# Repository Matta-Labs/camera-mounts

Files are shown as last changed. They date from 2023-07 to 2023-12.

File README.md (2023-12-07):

<!-- Improved compatibility of back to top link: See: https://github.com/othneildrew/Best-README-Template/pull/73 -->

<!--
*** Thanks for checking out the Best-README-Template. If you have a suggestion
*** that would make this better, please fork the repo and create a pull request
*** or simply open an issue with the tag "enhancement".
*** Don't forget to give the project a star!
*** Thanks again! Now go create something AMAZING! :D
-->

<!-- PROJECT SHIELDS -->
<!--
*** I'm using markdown "reference style" links for readability.
*** Reference links are enclosed in brackets [ ] instead of parentheses ( ).
*** See the bottom of this document for the declaration of the reference variables
*** for contributors-url, forks-url, etc. This is an optional, concise syntax you may use.
*** https://www.markdownguide.org/basic-syntax/#reference-style-links
-->
[][contributors-url]
[][forks-url]
[][stars-url]
[][issues-url]
[][license-url]
[][linkedin-url]

<!-- PROJECT LOGO -->
<br />
<div align="center">
  <a href="https://github.com/Matta-Labs/camera-mounts">
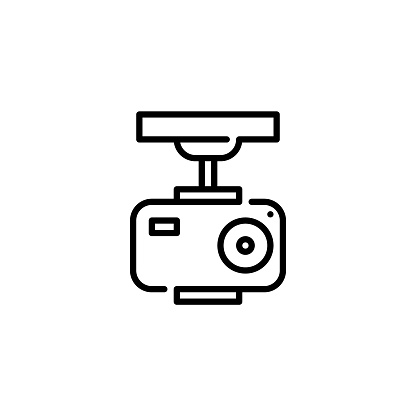
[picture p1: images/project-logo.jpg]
    
  </a>

<h3 align="center">Camera Mounts</h3>

  <p align="center">
    Welcome to the 3D Printer Camera Mounts GitHub repository! This project aims to provide a collection of camera mounts specifically for 3D printers. Attaching a camera to your printer allows for remote monitoring through OctoPrint or Klipper, time-lapse recording, and overall enhanced control of your printing processes.
    <br />
    <br />
    <a href="https://github.com/Matta-Labs/camera-mounts/issues">Report Problems</a>
    ·
    <a href="https://github.com/Matta-Labs/camera-mounts/issues">Request New Mounts!</a>
  </p>
</div>

<!-- ABOUT THE PROJECT -->
## About The Project ⚡️

<div  align="center" >
  Data engine
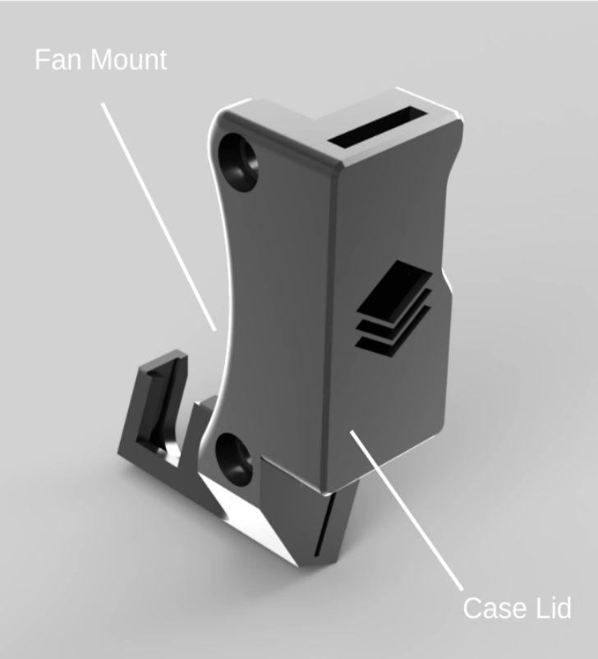
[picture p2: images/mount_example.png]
Mount example
  
  Close-up
</div>
<br />

At <a href="https://matta.ai"><strong>Matta</strong></a>, we use computer vision and AI to turbocharge 3D printing. Our work often results in the generation of printable hardware to allow cameras to be mounted to 3D printers.
<br />
<br />
We thought it would be helpful to the community to release these into the wild - and build an open source repository where new designs/improvements can be shared! 
<br />
<br />

<p align="right">(<a href="#readme-top">back to top</a>)</p>

### Introduction 🏁

Cameras mounted on 3D printers can be incredibly useful for various purposes. Whether you want to closely monitor your print progress, create stunning time-lapse videos, or remotely check on your printer's status, these 3D-printable camera mounts will come in handy. This repository serves as a hub for sharing various camera mount designs contributed by developers and designers in the community.
<br /><br />

### Built With 🛠️

[][Fusion-url]

<p align="right">(<a href="#readme-top">back to top</a>)</p>

<!-- USAGE EXAMPLES -->
## Usage ⚡️

The repo is broken-up into 3D printer brands. Navigate the repo to find your printer model, and browse the ReadMe's for printing/installation instruction. 
<br />
<br />
📸 Print, install and enjoy! Please leave feedback in FEEDBACK.md file within each mount directory.
<br />
<br />
All files should be accompanied by relevant documentation - raise an issue if not! 🚩
<p align="right">(<a href="#readme-top">back to top</a>)</p>

<!-- CONTRIBUTING -->
## Contributing 👏🏼

Contributions are what make the open source community such an amazing place to learn, inspire, and create. Any contributions you make are **greatly appreciated**.

If you have any exisiting camera mounts you are willing to share with the community, please do! We want to create the largest open source repo of 3D printer camera mounts on the internet! 

1. Fork the Project
2. Create a Branch for your Contribution (`git checkout -b Ultimaker-S5`)
3. Commit your Changes (`git commit -m 'Added nozzle mount for Ultimaker S5'`)
4. Push to the Branch (`git push origin Ultimaker-S5`)
5. Open a Pull Request

### Contribution Steps 💡

1. **Upload STL/STEP Files:** Upload or provide links to the STL/STEP files of the shared/developed camera mounts
2. **Camera Mount Demonstration:** Include images and GIFs demonstrating the installation and usage of the camera mounts.
3. **Document improvements you want to see:** If you know of any shortcomings of your designs, raise them in Issues! Someone may already have a solution for you!

<p align="right">(<a href="#readme-top">back to top</a>)</p>

<!-- ROADMAP -->
## Roadmap 🚴🏼‍♂️

- [x] Prusa
  - [x] i3 MK3S
    - [x] Nozzle camera
    - [ ] Bed camera

- [x] Creality
  - [x] Ender 3/Ender 3 Pro
    - [x] Nozzle camera
    - [ ] Bed camera
  - [x] Ender S1
    - [x] Nozzle camera
    - [ ] Bed camera
  - [x] CR-20
    - [x] Nozzle camera
    - [ ] Bed camera
- [ ] Ultimaker
- [ ] Voron
- [ ] Raise3D
- [ ] RatRig
- [ ] Makerbot
- [ ] BCN

See the [open issues](https://github.com/Matta-Labs/camera-mounts/issues) for a full list of proposed mount designs (and known issues).

<p align="right">(<a href="#readme-top">back to top</a>)</p>

<!-- LICENSE -->
## License 📄

Distributed under the MIT License. See `LICENSE.txt` for more information.

<p align="right">(<a href="#readme-top">back to top</a>)</p>

<!-- MORE ABOUT MATTA -->
## More About Matta 🔷

<div  align="center" >
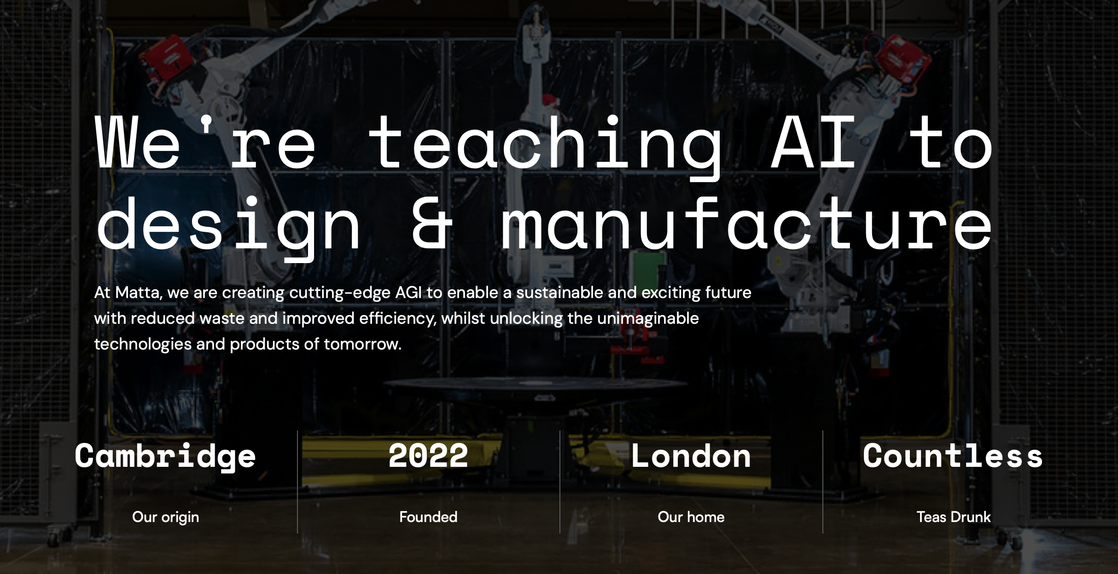
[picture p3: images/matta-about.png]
Data engine
  
</div>

At <a href="https://matta.ai"><strong>Matta</strong></a>, we are building AI to push the boundaries of manufacturing. We train neural networks using vision to become manufacturing copilots, enabling next-generation error correction, material qualitification and part QC.

<a href="https://matta.ai/greymatta"><strong>Check out our first-iteration AI, Grey-1</strong></a>

<!-- CONTACT -->
## Contact 📞

Team Matta - [@mattaai](https://twitter.com/mattaai) - hello@matta.ai

Project Link: [https://github.com/Matta-Labs/camera-mounts](https://github.com/Matta-Labs/camera-mounts)

<p align="right">(<a href="#readme-top">back to top</a>)</p>

<!-- ACKNOWLEDGMENTS -->
## Acknowledgments

* [Complex Additive Materials Group, University of Cambridge](https://github.com/cam-cambridge)

<p align="right">(<a href="#readme-top">back to top</a>)</p>

<!-- MARKDOWN LINKS & IMAGES -->
<!-- https://www.markdownguide.org/basic-syntax/#reference-style-links -->
[contributors-shield]: https://img.shields.io/github/contributors/Matta-Labs/camera-mounts.svg?style=for-the-badge
[contributors-url]: https://github.com/Matta-Labs/camera-mounts/graphs/contributors
[forks-shield]: https://img.shields.io/github/forks/Matta-Labs/camera-mounts.svg?style=for-the-badge
[forks-url]: https://github.com/Matta-Labs/camera-mounts/network/members
[stars-shield]: https://img.shields.io/github/stars/Matta-Labs/camera-mounts.svg?style=for-the-badge
[stars-url]: https://github.com/Matta-Labs/camera-mounts/stargazers
[issues-shield]: https://img.shields.io/github/issues/Matta-Labs/camera-mounts.svg?style=for-the-badge
[issues-url]: https://github.com/Matta-Labs/camera-mounts/issues
[license-shield]: https://img.shields.io/github/license/Matta-Labs/camera-mounts.svg?style=for-the-badge
[license-url]: https://github.com/Matta-Labs/camera-mounts/blob/master/LICENSE.txt
[linkedin-shield]: https://img.shields.io/badge/-LinkedIn-black.svg?style=for-the-badge&logo=linkedin&colorB=555
[linkedin-url]: https://www.linkedin.com/company/mattaai
[de-gif]: images/data-engine.gif
[Fusion.360]: https://img.shields.io/badge/Autodesk-Fusion%20360-FC6E26?style=for-the-badge&logo=autodesk&logoColor=white
[Fusion-url]: https://autodesk.com/products/fusion360/overview

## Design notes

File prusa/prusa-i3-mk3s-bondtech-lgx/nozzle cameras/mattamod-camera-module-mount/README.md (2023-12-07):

<!-- WHEN SHARING MOUNTS, FILL OUT THIS TEMPLATE AND ADD AS 'README.md' IN MOUNT FOLDER-->

<!-- HEADER -->
<br />
<div align="center">
  <a href="https://github.com/Matta-Labs/camera-mounts">
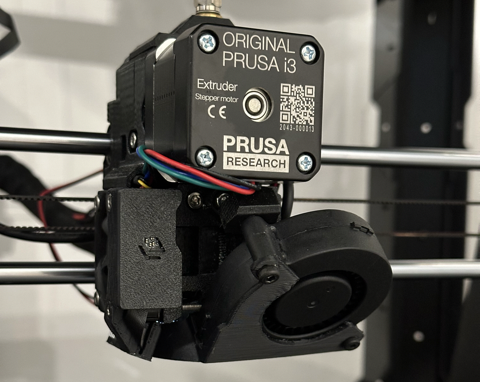
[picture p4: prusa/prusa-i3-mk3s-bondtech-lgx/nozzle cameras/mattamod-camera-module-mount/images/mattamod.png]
    
  </a>

<h3 align="center">Mount: MattaMod Prusa i3 MK3S Camera Module Mount (for BondTech LGX Extruder)</h3>

  <p align="center">
    This is a simple, two-piece mount to allow a cheap, off-the-shelf camera module to work as a nozzle camera for the Prusa i3 MK3S 3D printer fitted with the BondTech LGX extruder. 
    <br />
    <br />
    <a href="https://github.com/Matta-Labs/camera-mounts/issues">Report Problems</a>

  </p>
</div>

<!-- ABOUT THE PROJECT -->
## Mount Details

<b>Compatible Printer:</b> Prusa i3 MK3S (with BondTech LGX Extruder)
<br />
<br />
<b>Compatible Camera:</b> OV5640 Camera Module (66º Fixed Focus HD 5MP) - https://shorturl.at/bfxX8
<br />
<b>Other useful components:</b> Longer camera cable - https://shorturl.at/sCEY2, Heatsinks for camera module - https://shorturl.at/jQX79
<br />

### Built With 🛠️

* [][Fusion-url]

<!-- INSTALLATION -->
## Installation ⚡️

We recommend printing in ASA, for thermal resistance, PLA will quickly warp due to the heat of the camera.

<p>
  <b>Slicing/Printing</b>

  1. Slice with normal or tree supports, with the base of the mount flat against the bed.
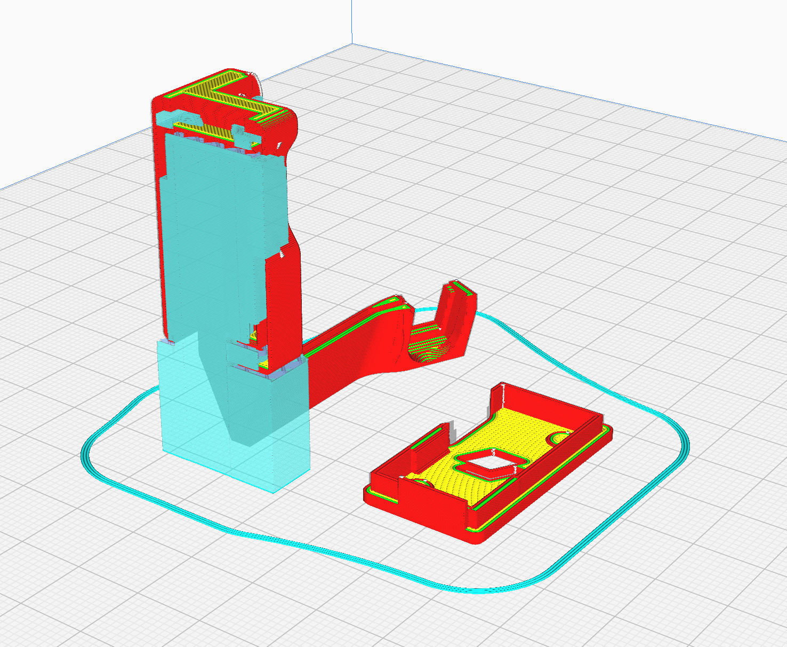
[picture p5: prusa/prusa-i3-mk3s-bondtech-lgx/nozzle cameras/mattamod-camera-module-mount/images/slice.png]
Slicing orientation
  
  2. We usually recommend a layer height of 0.2mm, and a brim for bed adhesion.
  <br>
  3. Print in ASA.
  <br />
  <br />
</p>
<p>
  <b>Installation</b>

  1. Carefully insert the camera unit into the housing, and press down until you feel a click.
  <br/>
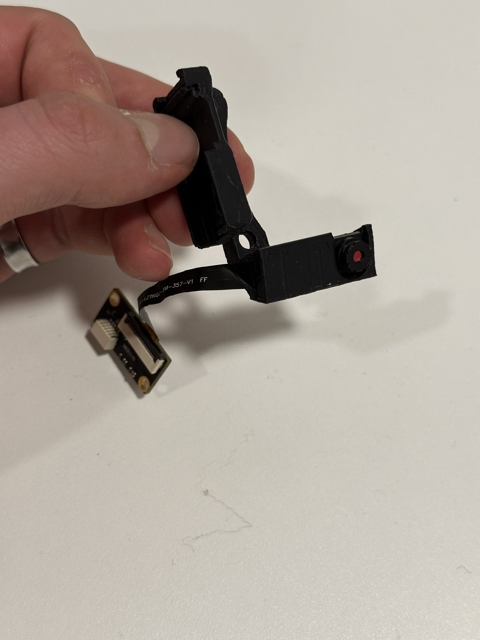
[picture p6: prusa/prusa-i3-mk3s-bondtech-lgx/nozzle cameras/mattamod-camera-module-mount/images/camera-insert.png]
Inserting camera unit
  
  <br/>
  2. Route the ribbon cable up into the board housing and carefully fold so that it is tucked behind the board
  <br/>
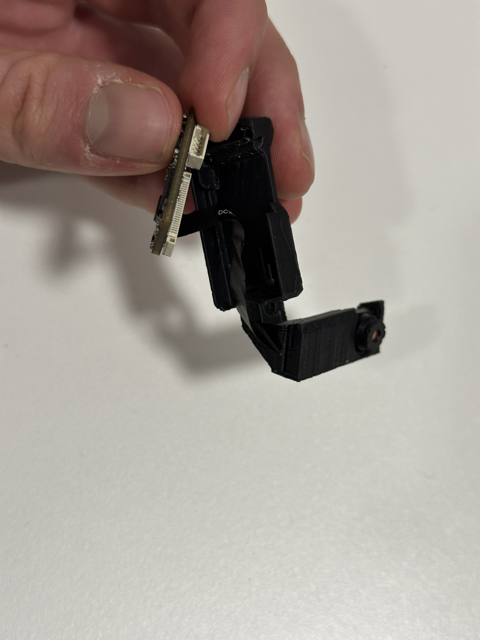
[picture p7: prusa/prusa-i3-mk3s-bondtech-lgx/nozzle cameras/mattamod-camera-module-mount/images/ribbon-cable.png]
Routing ribbon cable
  
  <br/>
  3. Click the board into place, and then cover with the case lid
  <br/>
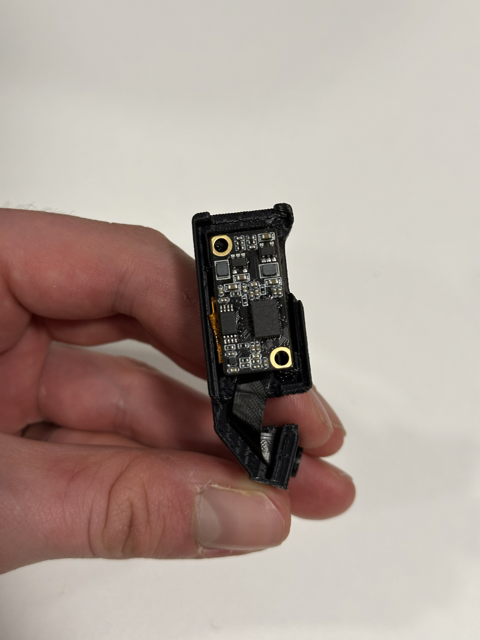
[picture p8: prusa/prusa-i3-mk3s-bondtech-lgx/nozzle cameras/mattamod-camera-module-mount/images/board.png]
Clipping board into mount
  
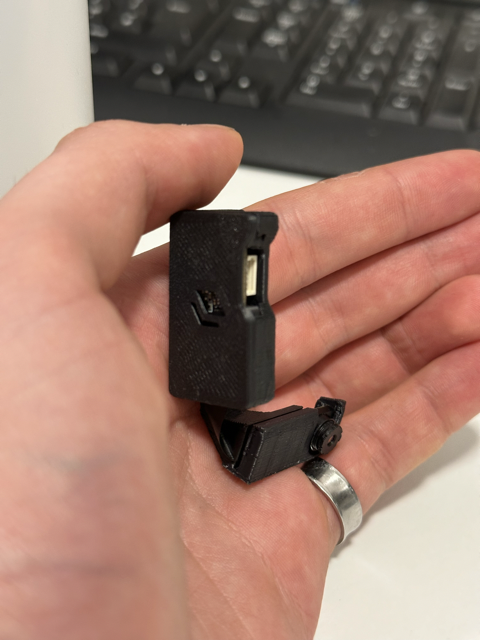
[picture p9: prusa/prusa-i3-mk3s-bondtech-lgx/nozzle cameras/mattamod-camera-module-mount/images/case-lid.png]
Clipping board into mount
  
  <br/>
  4. Add a 7x7x3mm heatsink to the back of the camera unit
  <br/>
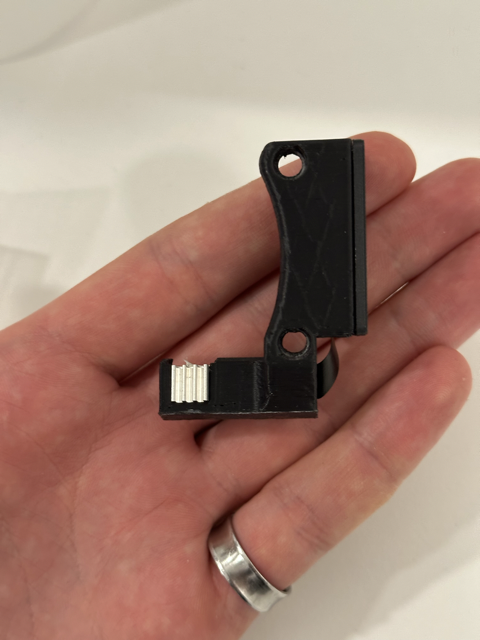
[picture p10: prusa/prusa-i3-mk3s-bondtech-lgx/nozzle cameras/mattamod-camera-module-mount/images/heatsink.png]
Adding heatsink
  
  <br/>
  5. Use two M3 20mm bolts to secure the mount to the right hand side of the hotend fan.
  <br/>
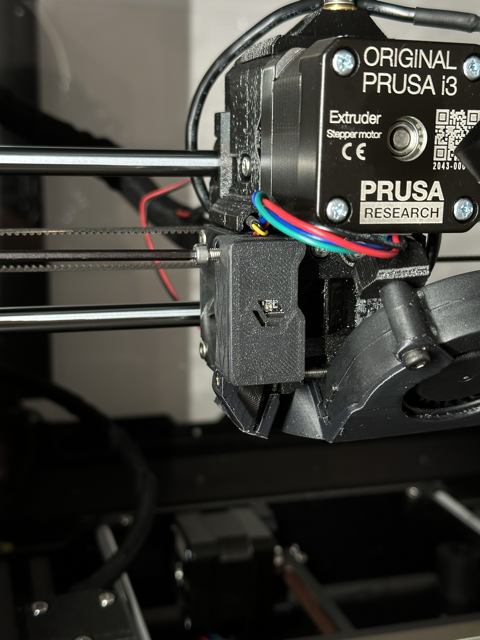
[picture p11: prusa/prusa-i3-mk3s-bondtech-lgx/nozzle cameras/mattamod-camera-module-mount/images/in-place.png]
Mount in place
  
  <br/>
  6. Route the camera cable as you wish, see our fs-cable-router or lgx-cable-router components for reference. We usually route the cable into the Prusa's cable sleeve for tidiness. The longer cable listed is helpful to ensure there is enough length to connect to your Pi/Laptop.
  <br />
</p>

<!-- Lighting -->
## Lighting (Example) 🔦

<p>

  The Prusa extruder occludes a lot of light, meaning the area under the nozzle is rather dark. To get around this, it is advantageous to build some kind of light source incident on the nozzle. 
  <br/>
  Below is an example of how we tackled this issue with our internal printers:

  <b>Required components:</b> Matta LED holder parts, 24 AWG wiring, Pre-wired LED - https://shorturl.at/gpvT9, Soldering Kit, Molex Crimp connector parts - https://shorturl.at/rvCX1, https://shorturl.at/mpruV

  1. Print LED holder in ASA. There are different versions of this for the standard and BondTech versions of the mount.
  <br/>
  <div>LED holder component</div>
  <br/>
  2. Solder the Pre-wired LED onto lengths of the 24 AWG wire, such that the wiring can be ran from the Einsey board, all the way to the nozzle.
  <br/> 
  <div>Wired LED</div>
  <br/>
  3. Use crimps to add the male Molex holder to the end of the LED wire
  <br/>
  <div>Molex head on LED cable</div>
  <br/>
  4. Connect the LED with the Molex connector to the highlighted, free port on the Einsey board.
  <br/>
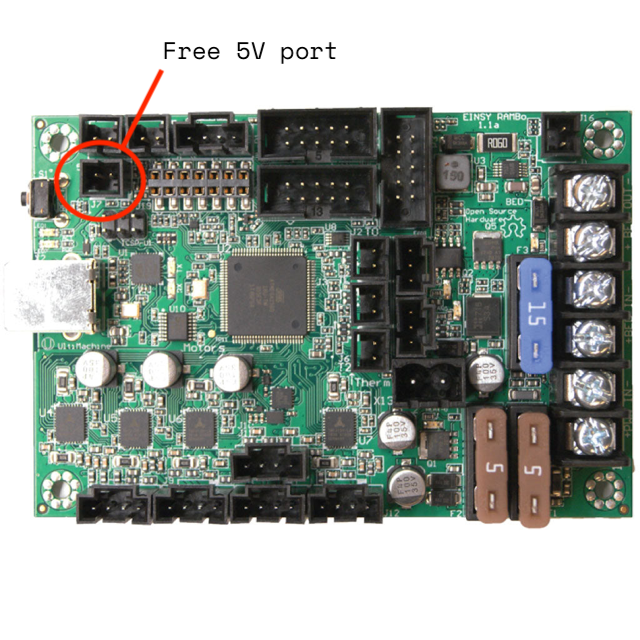
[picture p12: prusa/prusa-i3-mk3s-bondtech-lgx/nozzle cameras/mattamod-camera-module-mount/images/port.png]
Free port
  
  <br />
</p>

<br/>

📸 Print, install and enjoy! Please leave feedback for this mount in the appropriate FEEDBACK.md file.

<!-- LICENSE -->
## License 📄

Distributed under the MIT License. See `LICENSE.txt` for more information.

<!-- CONTACT -->
## Contact 📞

Tom Walker - [tomwalkr](https://github.com/tom-walkr) - tom@matta.ai

<!-- MARKDOWN LINKS & IMAGES -->
<!-- https://www.markdownguide.org/basic-syntax/#reference-style-links -->
[Fusion.360]: https://img.shields.io/badge/Autodesk-Fusion%20360-FC6E26?style=for-the-badge&logo=autodesk&logoColor=white
[Fusion-url]: https://autodesk.com/products/fusion360/overview

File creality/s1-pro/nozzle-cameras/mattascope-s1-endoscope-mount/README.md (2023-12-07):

<!-- WHEN SHARING MOUNTS, FILL OUT THIS TEMPLATE AND ADD AS 'README.md' IN MOUNT FOLDER-->

<!-- HEADER -->
<br />
<div align="center">
  <a href="https://github.com/Matta-Labs/camera-mounts">
    
  </a>

<h3 align="center">Mount: MattaScope S1 Endoscope Mount </h3>

  <p align="center">
    This is a simple, one-piece mount to allow a cheap, off-the-shelf endoscope to work as a nozzle camera for Creality Ender S1 printers (or printer with a Sprite Extruder)
    <br />
    <br />
    <a href="https://github.com/Matta-Labs/camera-mounts/issues">Report Problems</a>

  </p>
</div>

<!-- ABOUT THE PROJECT -->
## Mount Details

<b>Compatible Printer:</b> Creality Ender S1/S1 Pro (or anything with a Sprite Extruder)
<br />
<br />
<b>Compatible Camera:</b> Pancellent Auto Focus Endoscope 1944P HD Borescope Camera - https://shorturl.at/osMPY, https://shorturl.at/nquC0 
<br />

### Built With 🛠️

* [][Fusion-url]

<!-- INSTALLATION -->
## Installation ⚡️

Mount installation is simple - requiring no other components or tools! We recommend printing in ASA, for thermal resistance, PLA will quickly warp due to the heat of the camera.

<p>
  <b>Slicing/Printing</b>

  1. Slice with normal or tree supports, with the mounting plate flat against the bed.
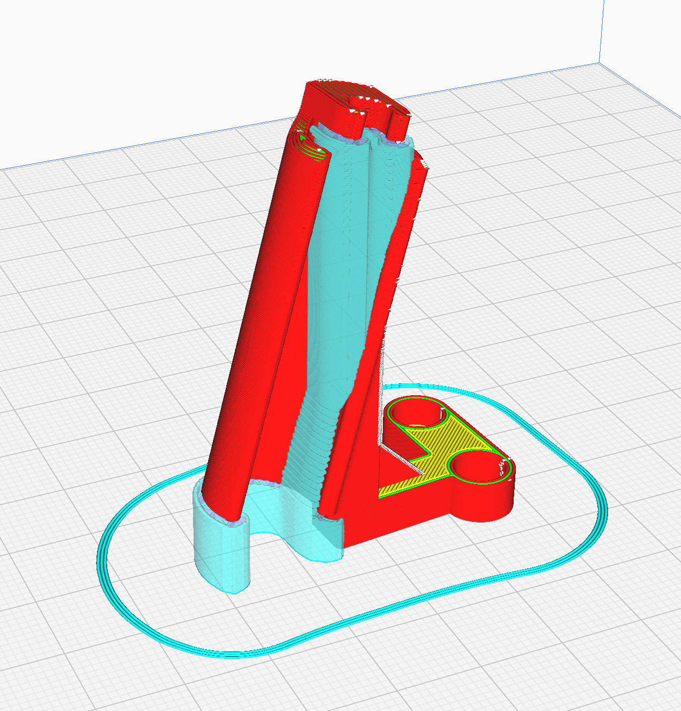
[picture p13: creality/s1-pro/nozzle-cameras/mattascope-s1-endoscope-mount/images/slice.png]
Slicing orientation
  
  2. We usually recommend a layer height of 0.2mm, and a brim for bed adhesion.
  <br>
  3. Print in ASA for longevity, but PLA works fine also.
  <br />
  <br />
</p>
<p>
  <b>Installation</b>

  1. Clip the endoscope into the mount, and secure the cable by pushing it into the clasp.
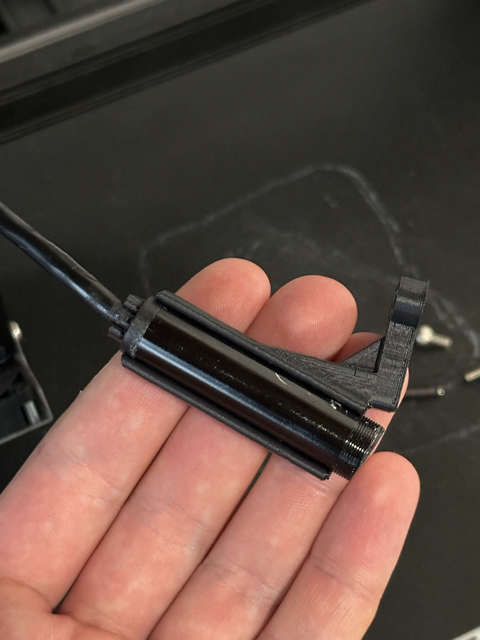
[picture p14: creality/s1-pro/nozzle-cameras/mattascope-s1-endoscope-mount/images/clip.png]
Clipping endoscope into mount
  
  2. Screw the mount onto the mounting holes on the right hand side of the extruder
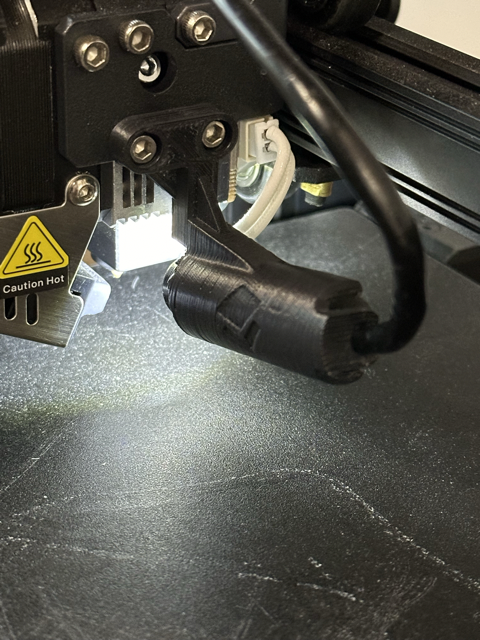
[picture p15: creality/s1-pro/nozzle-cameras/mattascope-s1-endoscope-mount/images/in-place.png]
Mount in place
  
  <br />
</p>

Set focus with ```sudo v4l2-ctl --set-ctrl focus_automatic_continuous=0``` & 
```sudo v4l2-ctl --set-ctrl focus_absolute=530```

<br/>

If using a Raspberry Pi, you can ensure these commands run on boot, and therefore are saved by adding these two lines to ```/etc/rc.local``` with ```sudo nano /etc/rc.local``` from root.

<br/>

📸 Print, install and enjoy! Please leave feedback for this mount in the appropriate FEEDBACK.md file.

<!-- LICENSE -->
## License 📄

Distributed under the MIT License. See `LICENSE.txt` for more information.

<!-- CONTACT -->
## Contact 📞

Tom Walker - [tomwalkr](https://github.com/tom-walkr) - tom@matta.ai

<!-- ACKNOWLEDGMENTS -->
## Acknowledgments

Credit to Douglas Brion for original ideation/design and to Christos Margadji for revision and printability improvements.

* [Douglas Brion](https://github.com/dougbrion)
* [Christos Margadji](https://github.com/cemag1)

<!-- MARKDOWN LINKS & IMAGES -->
<!-- https://www.markdownguide.org/basic-syntax/#reference-style-links -->
[Fusion.360]: https://img.shields.io/badge/Autodesk-Fusion%20360-FC6E26?style=for-the-badge&logo=autodesk&logoColor=white
[Fusion-url]: https://autodesk.com/products/fusion360/overview

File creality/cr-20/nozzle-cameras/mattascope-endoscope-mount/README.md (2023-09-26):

<!-- WHEN SHARING MOUNTS, FILL OUT THIS TEMPLATE AND ADD AS 'README.md' IN MOUNT FOLDER-->

<!-- HEADER -->
<br />
<div align="center">
  <a href="https://github.com/Matta-Labs/camera-mounts">
    
  </a>

<h3 align="center">Mount: MattaScope Endoscope Mount </h3>

  <p align="center">
    This is a simple, one-piece mount to allow a cheap, off-the-shelf endoscope to work as a nozzle camera for a range of Creality Printers (Ender 3, Ender 3 Pro and CR-20 - need to test on others)
    <br />
    <br />
    <a href="https://github.com/Matta-Labs/camera-mounts/issues">Report Problems</a>

  </p>
</div>

<!-- ABOUT THE PROJECT -->
## Mount Details

<b>Compatible Printer:</b> Creality Ender 3 Pro
<br />
<br />
<b>Compatible Camera:</b> Pancellent Auto Focus Endoscope 1944P HD Borescope Camera - https://shorturl.at/osMPY, https://shorturl.at/nquC0 
<br />

### Built With 🛠️

* [][Fusion-url]

<!-- INSTALLATION -->
## Installation ⚡️

Mount installation is simple - requiring no other components or tools! We recommend printing in ASA, for thermal resistance - PLA will quickly warp due to the heat of the camera.

<p>
  <b>Slicing/Printing</b>

  1. Slice with normal or tree supports, with the cable holder flat against the bed.
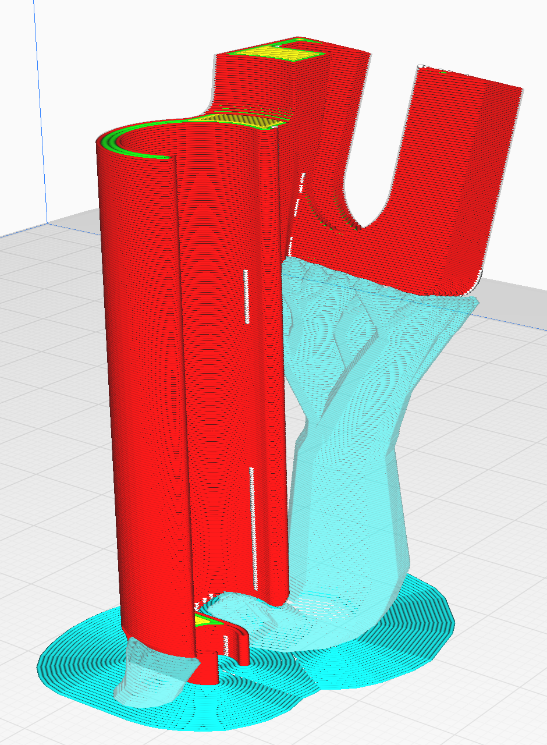
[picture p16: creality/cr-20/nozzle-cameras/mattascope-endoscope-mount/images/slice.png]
Slicing orientation
  
  2. We usually recommend a layer height of 0.2mm, and a brim for bed adhesion.
  <br>
  3. Print in ASA for longevity, but PLA works fine also.
  <br />
  <br />
</p>
<p>
  <b>Installation</b>

  1. Clip the endoscope into the mount, and secure the cable by pushing it into the clasp.
  <div>Clipping endoscope into mount</div>
  2. Locate the right-hand belt holder behind the extruder head
  <div>Belt holder</div>
  3. Carefully push the mount onto the belt holder - until the back wall of the mounting clip is fully underneath the X-axis extrusion.
  <div>Mount in place</div>
  <br />
</p>

If used with the recommended endoscope, we have found the optimum focus value to be 530.

Set this with ```sudo v4l2-ctl --set-ctrl focus_automatic_continuous=0``` & 
```sudo v4l2-ctl --set-ctrl focus_absolute=530```

<br/>

If using a Raspberry Pi, you can ensure these commands run on boot, and therefore are saved by adding these two lines to ```/etc/rc.local``` with ```sudo nano /etc/rc.local``` from root.

<br/>

📸 Print, install and enjoy! Please leave feedback for this mount in the appropriate FEEDBACK.md file.

<!-- LICENSE -->
## License 📄

Distributed under the MIT License. See `LICENSE.txt` for more information.

<!-- CONTACT -->
## Contact 📞

Tom Walker - [tomwalkr](https://github.com/tom-walkr) - tom@matta.ai

<!-- ACKNOWLEDGMENTS -->
## Acknowledgments

Credit to Douglas Brion for original ideation/design and to Christos Margadji for revision and printability improvements.

* [Douglas Brion](https://github.com/dougbrion)
* [Christos Margadji](https://github.com/cemag1)

<!-- MARKDOWN LINKS & IMAGES -->
<!-- https://www.markdownguide.org/basic-syntax/#reference-style-links -->
[Fusion.360]: https://img.shields.io/badge/Autodesk-Fusion%20360-FC6E26?style=for-the-badge&logo=autodesk&logoColor=white
[Fusion-url]: https://autodesk.com/products/fusion360/overview

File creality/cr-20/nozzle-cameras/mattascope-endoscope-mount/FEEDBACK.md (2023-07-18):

<!-- WHEN SHARING MOUNTS, FILL OUT THIS TEMPLATE AND ADD AS 'README.md' IN MOUNT FOLDER-->

<!-- HEADER -->
<br />
<div align="center">
  <a href="https://github.com/Matta-Labs/camera-mounts">
    <!-- PLEASE UPLOAD IMAGE OF MOUNT TO IMAGES/ AND ADD IT HERE-->
    
  </a>

<h3 align="center">Mount: MattaScope Endoscope Holder for Creality CR-20 </h3>

  <p align="center">
    This is the FEEDBACK.md file for this mount. Users can leave feedback on their experience of the mount in this file, suggest design changes and raise compatibility issues.
    <br />
    <br />
    <a href="https://github.com/Matta-Labs/camera-mounts/issues">Report Problems</a>

  </p>
</div>

<!-- FEEDBACK -->
## User Feedback ⚡️

Please leave feedback below!

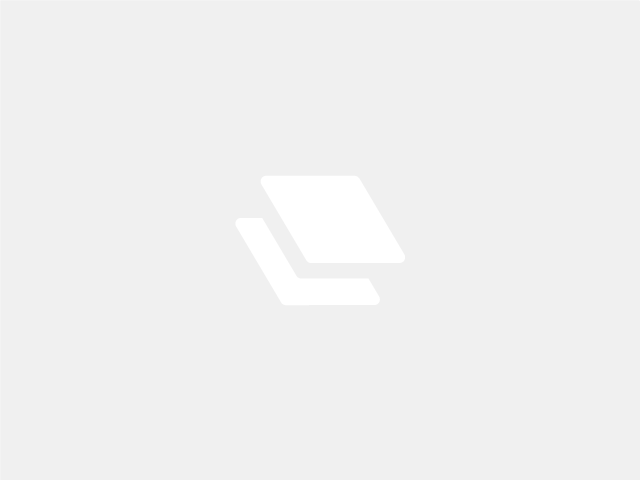
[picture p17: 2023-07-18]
images/placeholder.png

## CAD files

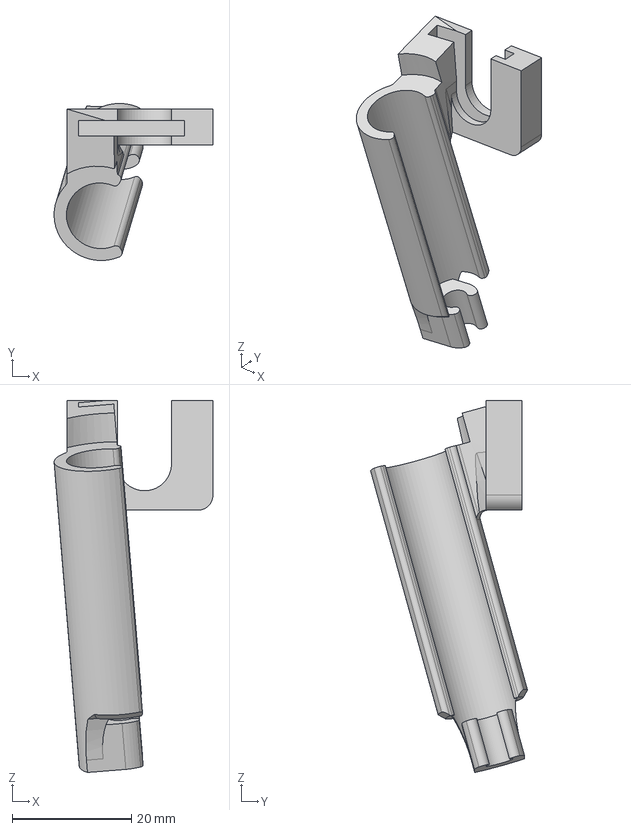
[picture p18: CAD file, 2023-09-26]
creality/cr-20/nozzle-cameras/mattascope-endoscope-mount/mattascope-endomount.step
26.6 x 26.3 x 62.3 mm

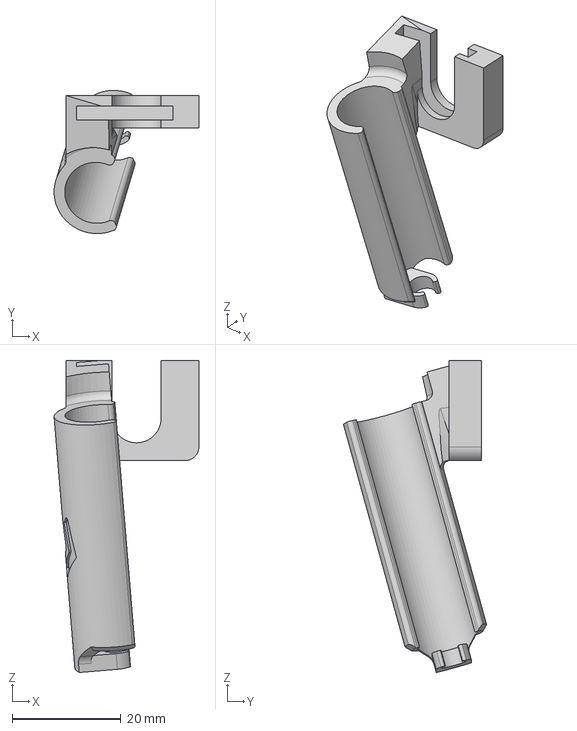
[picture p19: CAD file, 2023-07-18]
creality/cr-20/nozzle-cameras/mattascope-endscope-mount/creality-cr20-mattascope-endomount.step
26.6 x 26.3 x 57.3 mm

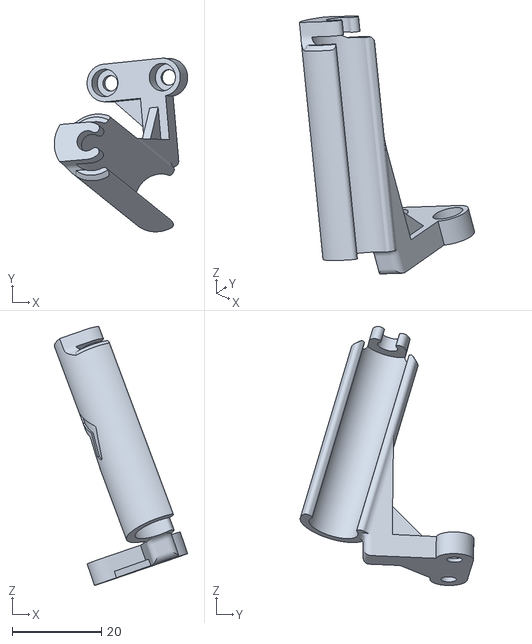
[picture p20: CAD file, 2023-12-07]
creality/s1-pro/nozzle-cameras/mattascope-s1-endoscope-mount/mattascope-s1-endoscope-mount.stl
29.9 x 39.0 x 58.1

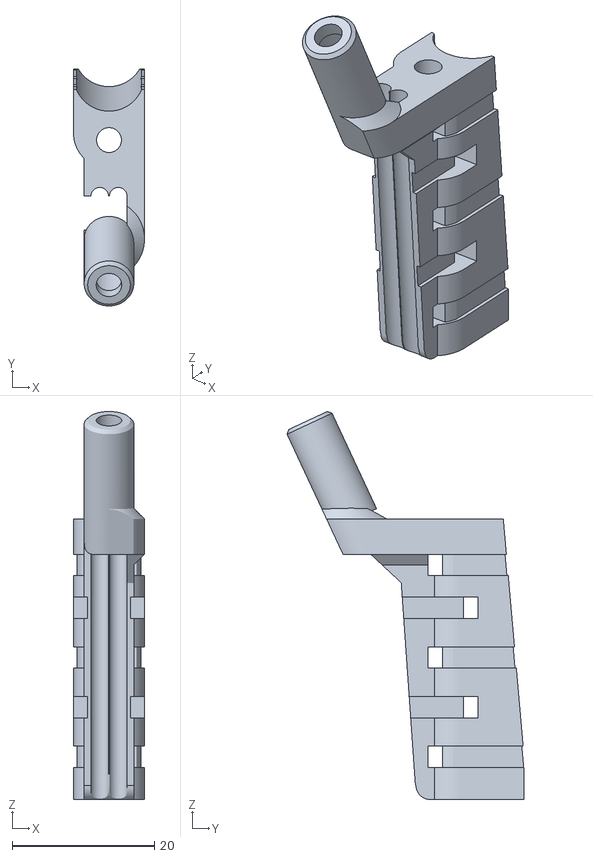
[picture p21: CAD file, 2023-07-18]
prusa/prusa-i3-mk3s-bondtech-lgx/nozzle cameras/mattamod-camera-module-mount/lighting/prusa-i3-mk3s-lgx-led-mount.stl
10.0 x 33.4 x 54.6

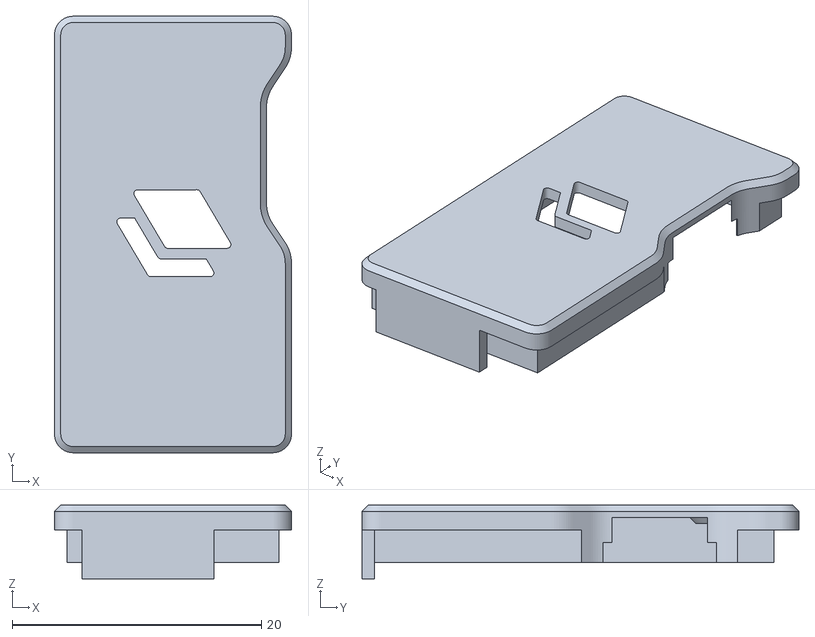
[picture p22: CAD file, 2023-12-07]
prusa/prusa-i3-mk3s-bondtech-lgx/nozzle cameras/mattamod-camera-module-mount/prusa-i3-mk3s-lgx-mattamod-case-lid.stl
19.0 x 35.0 x 5.93

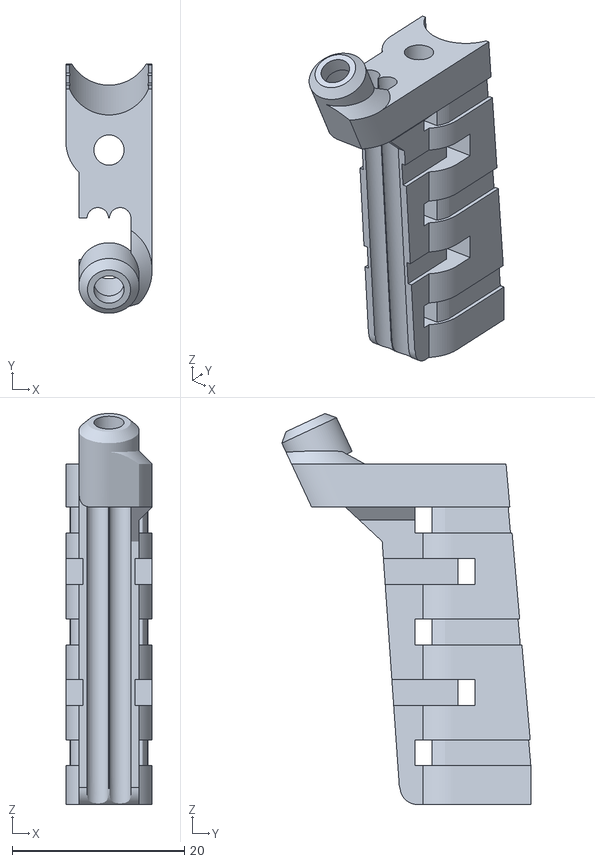
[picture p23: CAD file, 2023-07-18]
prusa/prusa-i3-mk3s/nozzle-cameras/mattamod-camera-module-mount/lighting/prusa-i3-mk3s-mattamod-led-mount.stl
10.0 x 28.9 x 45.3

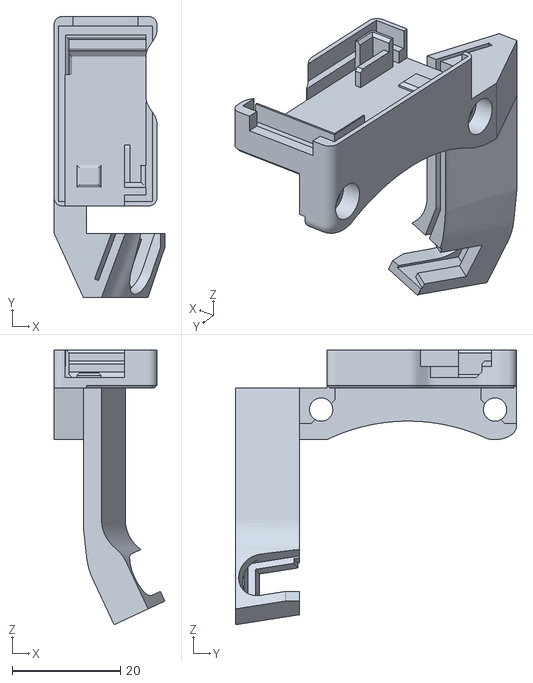
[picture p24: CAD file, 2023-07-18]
prusa/prusa-i3-mk3s-bondtech-lgx/nozzle cameras/mattamod-camera-module-mount/prusa-i3-mk3s-lgx-mattamod-mount-body.stl
20.5 x 51.9 x 50.7

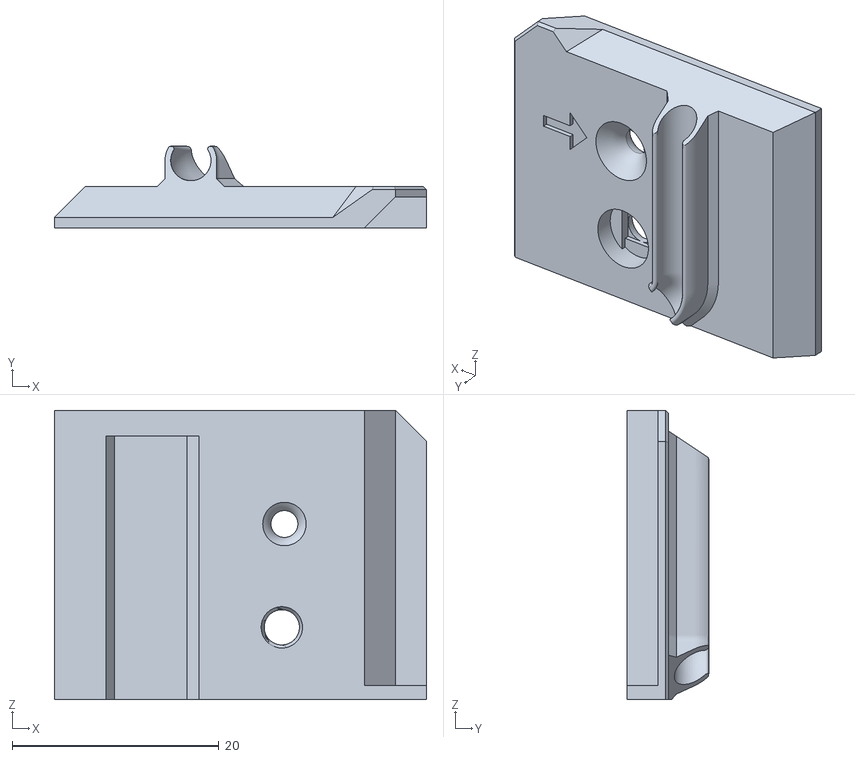
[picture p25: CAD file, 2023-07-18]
prusa/prusa-i3-mk3s/nozzle-cameras/mattamod-camera-module-mount/prusa-i3-mk3s-mattamod-fs-cable-router.stl
36.0 x 7.89 x 28.0

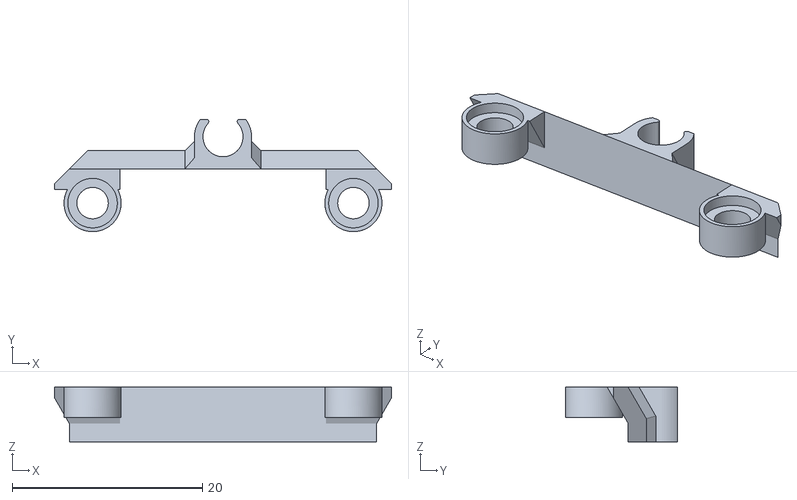
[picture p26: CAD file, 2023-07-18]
prusa/prusa-i3-mk3s-bondtech-lgx/nozzle cameras/mattamod-camera-module-mount/prusa-i3-mk3s-lgx-cable-router.stl
35.4 x 11.8 x 5.73

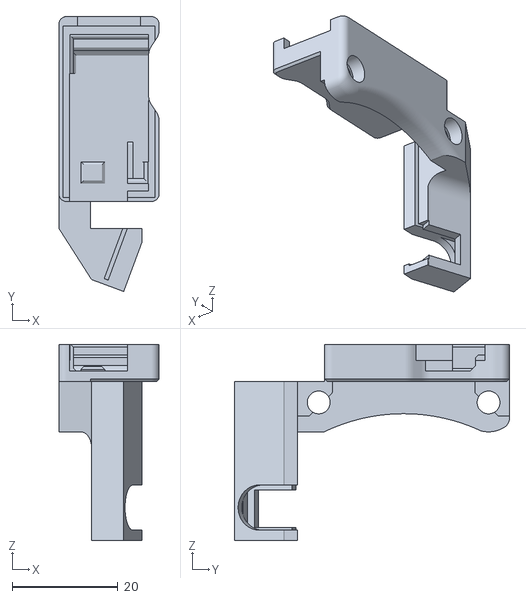
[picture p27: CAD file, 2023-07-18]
prusa/prusa-i3-mk3s/nozzle-cameras/mattamod-camera-module-mount/prusa-i3-mk3s-mattamod-mount-body.stl
19.0 x 52.0 x 37.1

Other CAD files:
creality/cr-20/nozzle-cameras/mattascope-endoscope-mount/mattascope-endomount.stl
creality/cr-20/nozzle-cameras/mattascope-endoscope-mount/old-versions/creality-cr20-mattascope-endomount.stl
creality/cr-20/nozzle-cameras/mattascope-endscope-mount/creality-cr20-mattascope-endomount.stl
creality/ender-3-pro/nozzle-cameras/mattascope-endoscope-mount/mattascope-endomount.stl
creality/ender-3-pro/nozzle-cameras/mattascope-endoscope-mount/old-versions/creality-ender3-pro-mattascope-endomount.stl
creality/ender-3-pro/nozzle-cameras/mattascope-endscope-mount/creality-ender3-pro-mattascope-endomount.stl
creality/ender-3/nozzle-cameras/mattascope-endoscope-mount/mattascope-endomount.stl
creality/ender-3/nozzle-cameras/mattascope-endoscope-mount/old-versions/creality-ender3-mattascope-endomount.stl
creality/ender-3/nozzle-cameras/mattascope-endscope-mount/creality-ender3-mattascope-endomount.stl

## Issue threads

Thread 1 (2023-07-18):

No documentation for MattaMod Camera Module Mount for Prusa i3 MK3S (and BondTech)

tom-walkr, 2023-07-18:
I have added the STLs, but not got round to adding documentation. I will also add STEP files.

Zarnack, 2023-12-04:
Hi,
is there an estimated timeframe for adding some documentation? Especially a link to the used camera module would be very appreciated!

tom-walkr, 2023-12-04:
Hi! Apologies for the delay in writing up! I will set myself a goal to get documentation up in the next two weeks.

In the meantime - here is a link to the camera module we use with this mount:

https://www.aliexpress.us/item/3256804790797706.html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

The 66°, Fixed Focus model is best for the job!

Closed 2023-12-07.

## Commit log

2023-07-18 Added MattaScope Mount, and Doc templates
    [creality-ender3-mattascope-endomount.step, creality-ender3-mattascope-endomount.stl, prusa-i3-mk3s-lgx-cable-router.stl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]
2023-07-18 Added Ender 3 Pro and CR-20 support
    [creality-cr20-mattascope-endomount.step, creality-cr20-mattascope-endomount.stl, creality-ender3-pro-mattascope-endomount.step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]
2023-07-18 Adding placeholder images to improve folder system again
    [prusa-i3-mk3s-lgx-cable-router.stl, prusa-i3-mk3s-lgx-led-mount.stl, prusa-i3-mk3s-lgx-mattamod-case-lid.stl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]
2023-09-26 fix: :zap: Upgraded mattascope mount with better cable grip
    The cable grip of the MattaScope (endoscope mount for Creality printers) frequently broke on testing. A heavier-duty cable grip has been added. Also tolerancing has been adjusted slightly to grip the scope a bit more.
    [creality-cr20-mattascope-endomount.step, creality-cr20-mattascope-endomount.stl, creality-ender3-mattascope-endomount.step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]
2023-09-27 Fixed typos
    [creality-cr20-mattascope-endomount.step, creality-cr20-mattascope-endomount.stl, creality-ender3-mattascope-endomount.step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]
2023-12-07 feat: :sparkles: Added MattaScope for Ender S1 (and other Sprite Extruder printers)
    [mattascope-s1-endoscope-mount.stl]
2023-12-07 docs: :memo: Documentation for MattaMod mounts for Prusa i3 MK3S and BondTech LGX extruder
    [prusa-i3-mk3s-lgx-mattamod-case-lid.stl, prusa-i3-mk3s-mattamod-case-lid.stl]
